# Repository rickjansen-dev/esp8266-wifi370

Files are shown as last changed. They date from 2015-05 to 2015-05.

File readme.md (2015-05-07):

esp8266-wifi370
==================

Implementation of the wifi370 protocol to connect cheap RGB ledstrips to pimatic using a esp8266.
Currently this repository contains the following:

 - Lua scripts to run on NodeMCU firmware
 - Eagle PCB schematic & board layout

## Quick how-to setup

- Install [pimatic] and the excellent [pimatic-led-light] plugin
- Install NodeMCU on the esp8266, connect it to your wifi & upload the lua scripts (ESPlorer is a nice tool to do this)

For the pimatic-led-light configuration, use wifi370 as the device parameter.
It's probably a good idea to set up your router's DHCP server so your esp8266 will get the same IP address every time.

## Eagle PCB schematic & board layout

There's a PCB schematic & board layout in the repository. The PCB contains the ESP-03, a voltage regulator, a power input & 3 logic gate MOSFETs to control the RGB channels of the ledstrip. See my blog at [auspex.nl] for a more detailed explanation.

## Demo video

I recorded a demonstration video, you can watch it [here].  
I am aware of VVS, it was just easier to get everything on screen and use my mouse at the same time =]

## Known bugs

- The PWM output sometimes glitches due to being software-based PWM. It only really flickers when moving from one color to another. 
- The output color is stored in the esp8266's flash memory. The pimatic-led-light UI can output a lot of values in a short amount of time which leads to lots of writes to the flash memory. I am unsure if this will be a problem and if the esp8266's flash can become corrupt. Use at your own risk.
- The on-off state might not always be in the correct state, as the wifi370 protocol implementation is very basic.

[pimatic]:http://pimatic.org
[pimatic-led-light]:https://github.com/philip1986/pimatic-led-light
[auspex.nl]:http://auspex.nl
[here]:http://youtu.be/MzmGHIzuEzY

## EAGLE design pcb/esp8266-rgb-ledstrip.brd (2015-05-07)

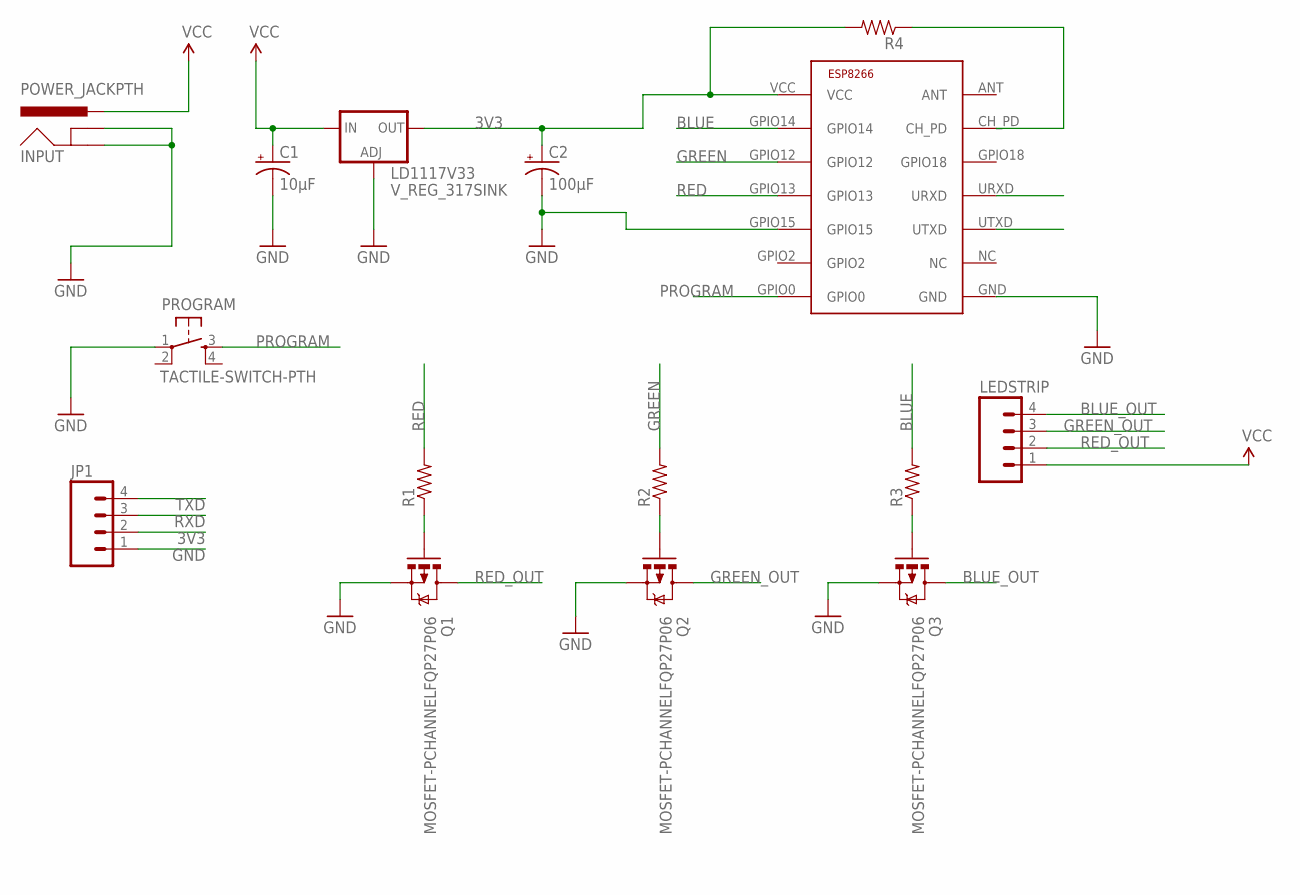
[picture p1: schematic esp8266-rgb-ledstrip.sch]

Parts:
C1: 10µF; CPOL-RADIAL-10UF-25V
C2: 100µF; CPOL-RADIAL-100UF-25V
INPUT: POWER_JACKPTH; POWER_JACK_PTH
JP1: M04PTH; 1X04
LD1117V33: V_REG_317SINK; TO220-ADJ
LEDSTRIP: M04PTH; 1X04
PROGRAM: TACTILE-SWITCH-PTH; TAC-SWITCH-PTH
Q1, Q2, Q3: MOSFET-PCHANNELFQP27P06; TO220V
R1, R2, R3, R4: RESISTORAXIAL-0.3; AXIAL-0.3
U$1: ESP8266-03; ESP-03

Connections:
3V3: C2.1 (+), JP1.2, LD1117V33.OUT, R4.P$2 (2), U$1.VCC
BLUE: R3.P$2 (2), U$1.GPIO14
BLUE_OUT: LEDSTRIP.4, Q3.2 (D)
BLUE_R: Q3.1 (G), R3.P$1 (1)
GND: C1.2 (-), C2.2 (-), INPUT.GND, INPUT.GNDBREAK, JP1.1, LD1117V33.ADJ, PROGRAM.1, Q1.3 (S), Q2.3 (S), Q3.3 (S), U$1.GND, U$1.GPIO15
GREEN: R2.P$2 (2), U$1.GPIO12
GREEN_OUT: LEDSTRIP.3, Q2.2 (D)
GREEN_R: Q2.1 (G), R2.P$1 (1)
unnamed: R4.P$1 (1), U$1.CH_PD
PROGRAM: PROGRAM.3, U$1.GPIO0
RED: R1.P$2 (2), U$1.GPIO13
RED_OUT: LEDSTRIP.2, Q1.2 (D)
RED_R: Q1.1 (G), R1.P$1 (1)
RXD: JP1.3, U$1.URXD
TXD: JP1.4, U$1.UTXD
VCC: C1.1 (+), INPUT.PWR, LD1117V33.IN, LEDSTRIP.1

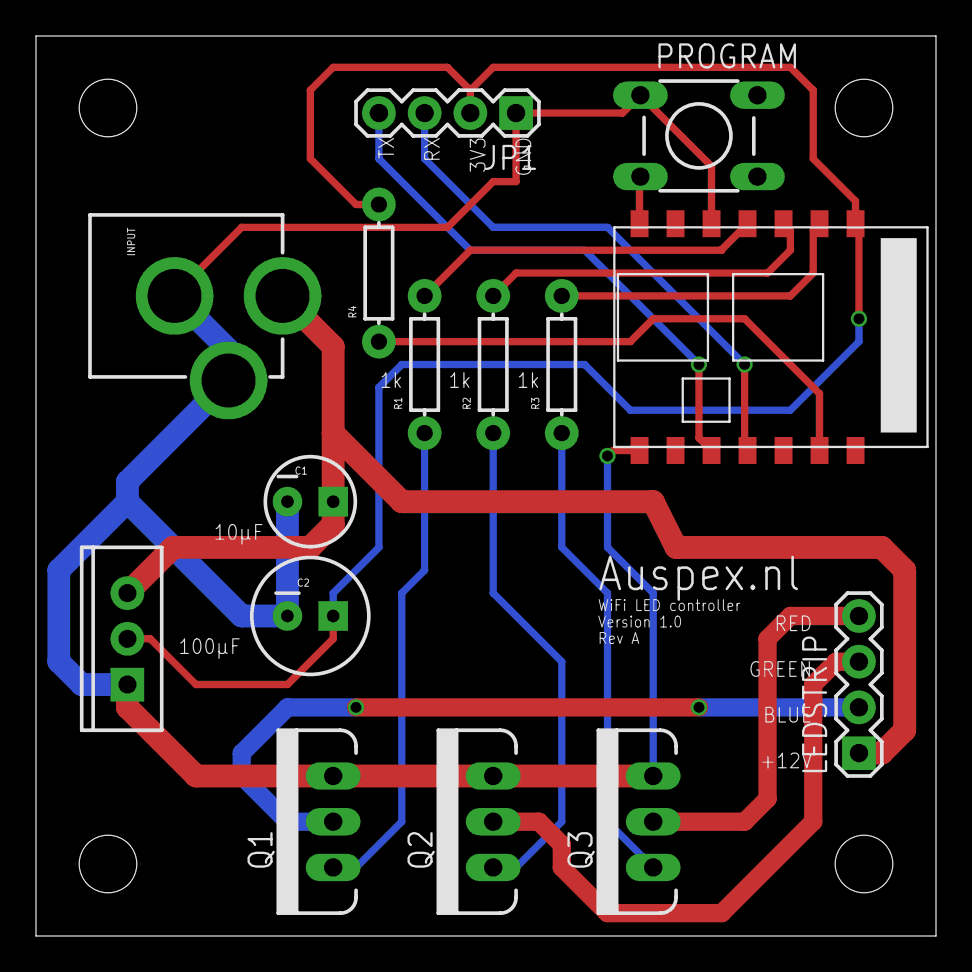
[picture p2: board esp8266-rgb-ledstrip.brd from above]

Board: 2 copper layers, 50.0 x 50.0 mm, 15 parts (0 on the bottom side), 16 nets.

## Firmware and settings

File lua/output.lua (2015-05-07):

pwm.setup(gpio_red, 100, r)
pwm.setup(gpio_green, 100, g)
pwm.setup(gpio_blue, 100, b)
pwm.start(gpio_red)
pwm.start(gpio_green)
pwm.start(gpio_blue)

tmr.alarm(6, 10, 1, function ()
        if (r > wanted_r) then
                r = r - 1 
                pwm.setduty(gpio_red,r)
        end
        if (r < wanted_r) then
                r = r + 1    
                pwm.setduty(gpio_red,r)     
        end
        if (g > wanted_g) then
                g = g - 1
                pwm.setduty(gpio_green,g)
        end
        if (g < wanted_g) then
                g = g + 1   
                pwm.setduty(gpio_green,g)       
        end
        if (b > wanted_b) then
                b = b - 1
                pwm.setduty(gpio_blue,b)
        end
        if (b < wanted_b) then
                b = b + 1    
                pwm.setduty(gpio_blue,b)      
        end   

end)

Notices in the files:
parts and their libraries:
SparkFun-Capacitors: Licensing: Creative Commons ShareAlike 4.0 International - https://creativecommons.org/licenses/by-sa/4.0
